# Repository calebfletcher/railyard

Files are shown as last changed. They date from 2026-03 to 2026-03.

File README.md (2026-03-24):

# railyard
An ecosystem of boards to interface with FPGA boards with PCIe interfaces

| Board  | Description | Location | Status |
| --- | --- | --- | --- |
| timemaster | Clock Generator | [boards/timemaster](boards/timemaster/) | Prototype Received |
| hub | Central Interface Hub | [boards/hub](boards/hub/) | In Design |

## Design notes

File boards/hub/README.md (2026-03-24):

# Hub

The central interface hub for railyard.

Provides the main PCIe connector to interface with the FPGA, and supplies power to it and to the various other connected boards.

pcb image

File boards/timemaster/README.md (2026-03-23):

# Timemaster

A Si5340-based clock generator board with two clocks available via a SATA connector, and 2 clocks available via MMCX connectors. All clocks are differential.

Includes a STM32G031G8Ux microcontroller to manage the Si5340, accessible over via I2C on the JST-GH connector.

5 debug LEDs are available to the STM32.

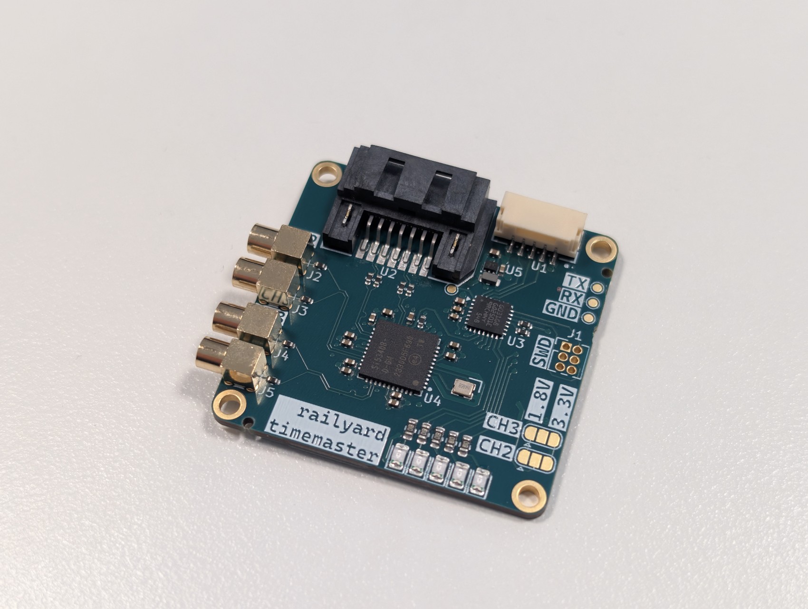
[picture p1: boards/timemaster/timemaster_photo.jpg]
pcb image


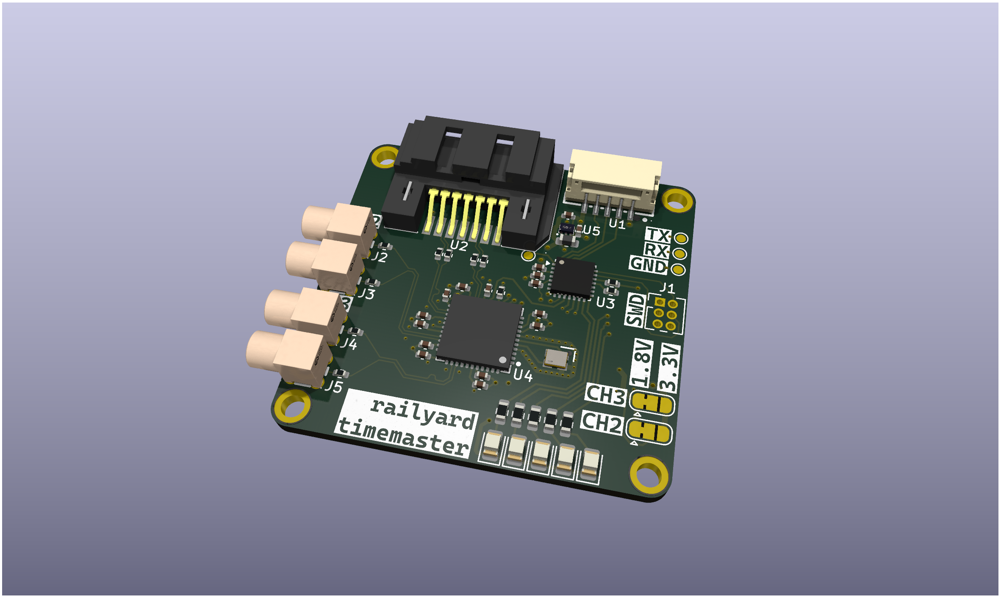
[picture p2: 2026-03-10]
boards/timemaster/timemaster_render.png

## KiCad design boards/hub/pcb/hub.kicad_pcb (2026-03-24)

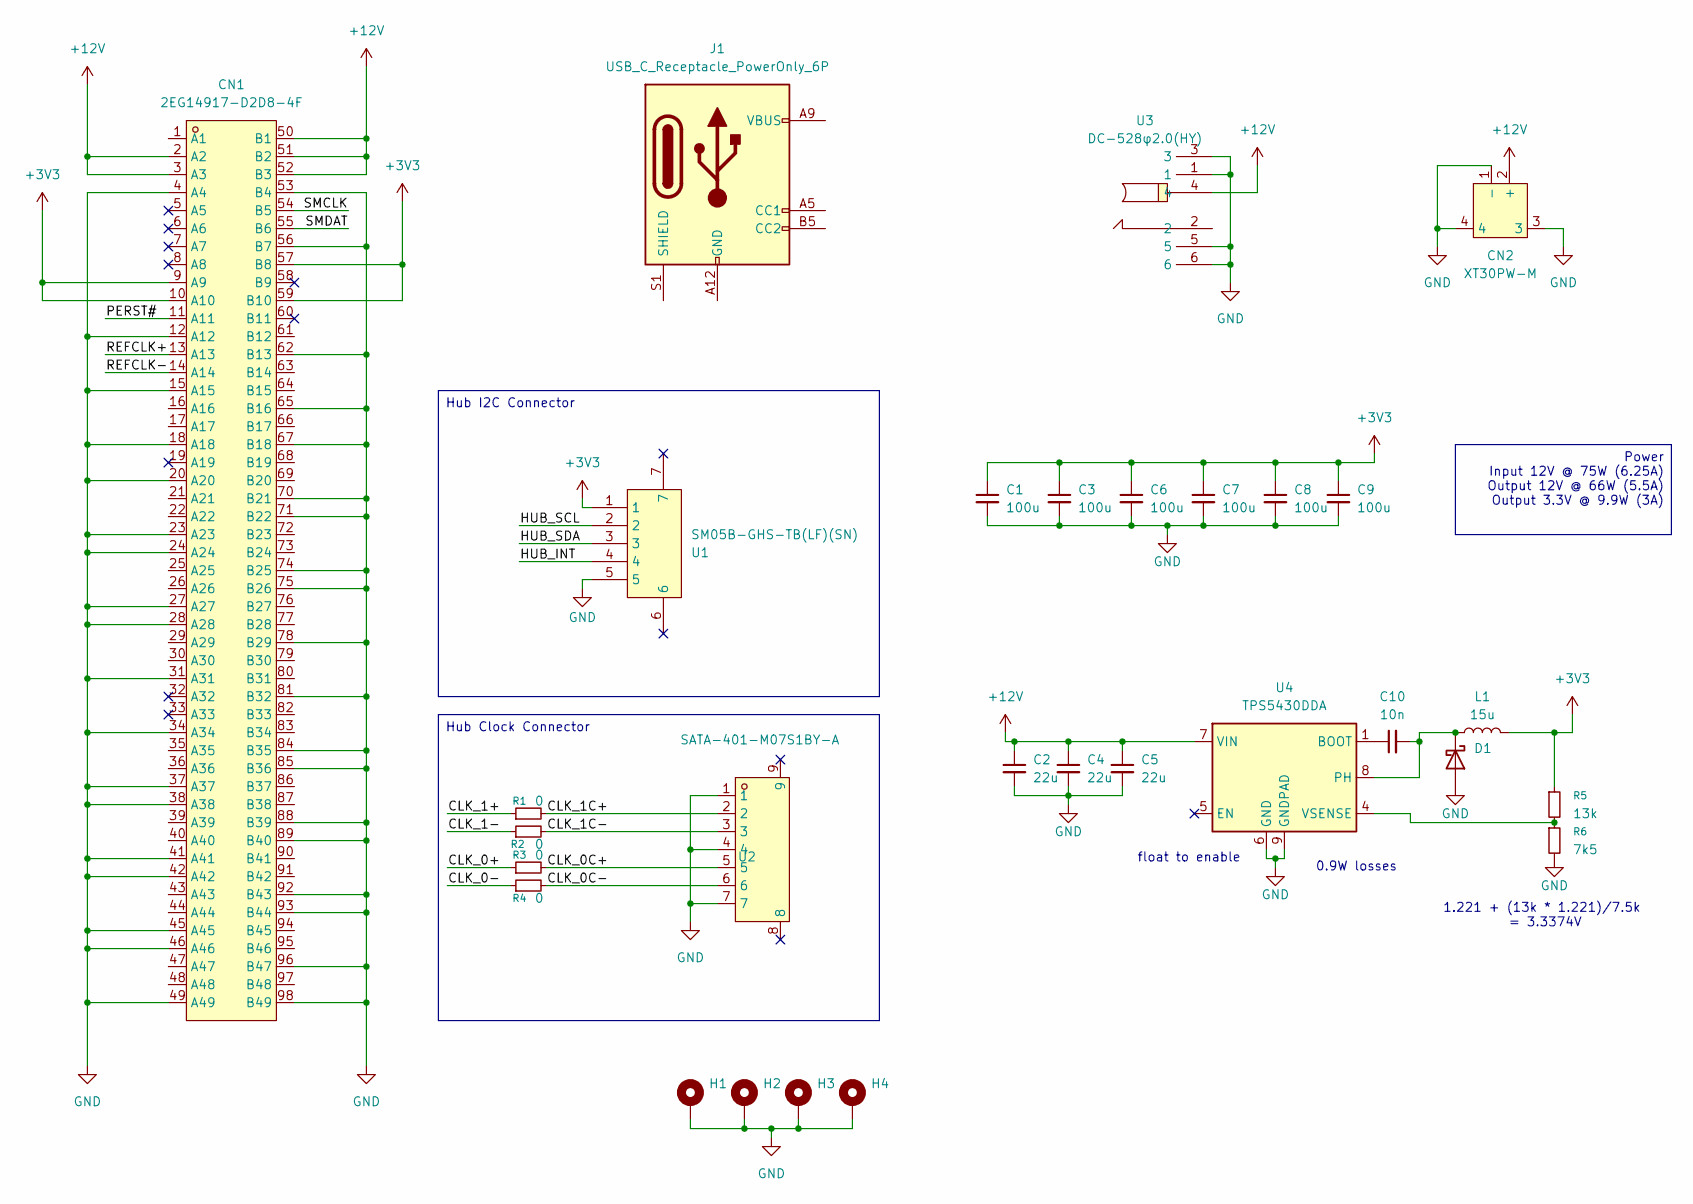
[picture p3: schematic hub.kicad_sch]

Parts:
C1, C3, C6, C7, C8, C9: 100u; C_1206_3216Metric; LCSC Part C15008
C2, C4, C5: 22u; C_0805_2012Metric; LCSC Part C45783
C10: 10n; C_0402_1005Metric; LCSC Part C15195
CN1: 2EG14917-D2D8-4F; CONN-TH_2EG14917-D2D8-4F; MPN 2EG14917-D2D8-4F; LCSC Part C426231
CN2: XT30PW-M; CONN-TH_XT30PW-M; LCSC Part C431092
D1: D_Schottky; D_SMA; LCSC Part C22452
H1, H2, H3, H4: MountingHole_Pad; MountingHole_2.2mm_M2_ISO7380_Pad
J1: USB_C_Receptacle_PowerOnly_6P; USB_C_Receptacle_GCT_USB4125-xx-x_6P_TopMnt_Horizontal
L1: 15u; L_Coilcraft_MSS1038-XXX; LCSC Part C18212714
R1, R2, R3, R4: 0; R_0402_1005Metric
R5: 13k; R_0603_1608Metric; LCSC Part C22797
R6: 7k5; R_0603_1608Metric; LCSC Part C23234
U1: SM05B-GHS-TB(LF)(SN); CONN-SMD_5P-P1.25_SM05B-GHS-TB-LF-SN; LCSC Part C189896
U2: SATA-401-M07S1BY-A; CONN-SMD_SATA-401-M07S1BY-A; LCSC Part C7500835
U3: DC-528φ2.0(HY); DC-IN-TH_DC-528-2.0-HY; LCSC Part C2851176
U4: TPS5430DDA; TI_SO-PowerPAD-8_ThermalVias; LCSC Part C9864

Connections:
+3V3: C1.1, C3.1, C6.1, C7.1, C8.1, C9.1, CN1.9 (A9), CN1.10 (A10), CN1.57 (B8), CN1.59 (B10), L1.2, R5.1, U1.1
+12V: C2.1, C4.1, C5.1, CN1.2 (A2), CN1.3 (A3), CN1.50 (B1), CN1.51 (B2), CN1.52 (B3), CN2.2 (+), U3.4, U4.7 (VIN)
/CLK_0+: R3.1
/CLK_0-: R4.1
/CLK_0C+: R3.2, U2.5
/CLK_0C-: R4.2, U2.6
/CLK_1+: R1.1
/CLK_1-: R2.1
/CLK_1C+: R1.2, U2.2
/CLK_1C-: R2.2, U2.3
/HUB_INT: U1.4
/HUB_SCL: U1.2
/HUB_SDA: U1.3
/PERST#: CN1.11 (A11)
/REFCLK+: CN1.13 (A13)
/REFCLK-: CN1.14 (A14)
/SMCLK: CN1.54 (B5)
/SMDAT: CN1.55 (B6)
GND: C1.2, C2.2, C3.2, C4.2, C5.2, C6.2, C7.2, C8.2, C9.2, CN1.4 (A4), CN1.12 (A12), CN1.15 (A15), CN1.18 (A18), CN1.20 (A20), CN1.23 (A23), CN1.24 (A24), CN1.27 (A27), CN1.28 (A28), CN1.31 (A31), CN1.34 (A34), CN1.37 (A37), CN1.38 (A38), CN1.41 (A41), CN1.42 (A42), CN1.45 (A45), CN1.46 (A46), CN1.49 (A49), CN1.53 (B4), CN1.56 (B7), CN1.62 (B13), CN1.65 (B16), CN1.67 (B18), CN1.70 (B21), CN1.71 (B22), CN1.74 (B25), CN1.75 (B26), CN1.78 (B29), CN1.81 (B32), CN1.84 (B35), CN1.85 (B36), CN1.88 (B39), CN1.89 (B40), CN1.92 (B43), CN1.93 (B44), CN1.96 (B47), CN1.98 (B49), CN2.1 (-), CN2.3, CN2.4, D1.2 (A), H1.1, H2.1, H3.1, H4.1, R6.2, U1.5, U2.1, U2.4, U2.7, U3.1, U3.3, U3.5, U3.6, U4.6 (GND), U4.9 (GNDPAD)
unnamed: C10.2, D1.1 (K), L1.1, U4.8 (PH)
unnamed: J1.A12 (GND), J1.B12 (GND)
unnamed: J1.A9 (VBUS), J1.B9 (VBUS)
unnamed: C10.1, U4.1 (BOOT)
unnamed: R5.2, R6.1, U4.4 (VSENSE)

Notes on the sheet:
0.9W losses
float to enable
1.221 + (13k * 1.221)/7.5k = 3.3374V
Power Input 12V @ 75W (6.25A) Output 12V @ 66W (5.5A) Output 3.3V @ 9.9W (3A)
Hub Clock Connector
Hub I2C Connector

Board: 2 copper layers, 27 parts (0 on the bottom side), 12 nets, no tracks yet.

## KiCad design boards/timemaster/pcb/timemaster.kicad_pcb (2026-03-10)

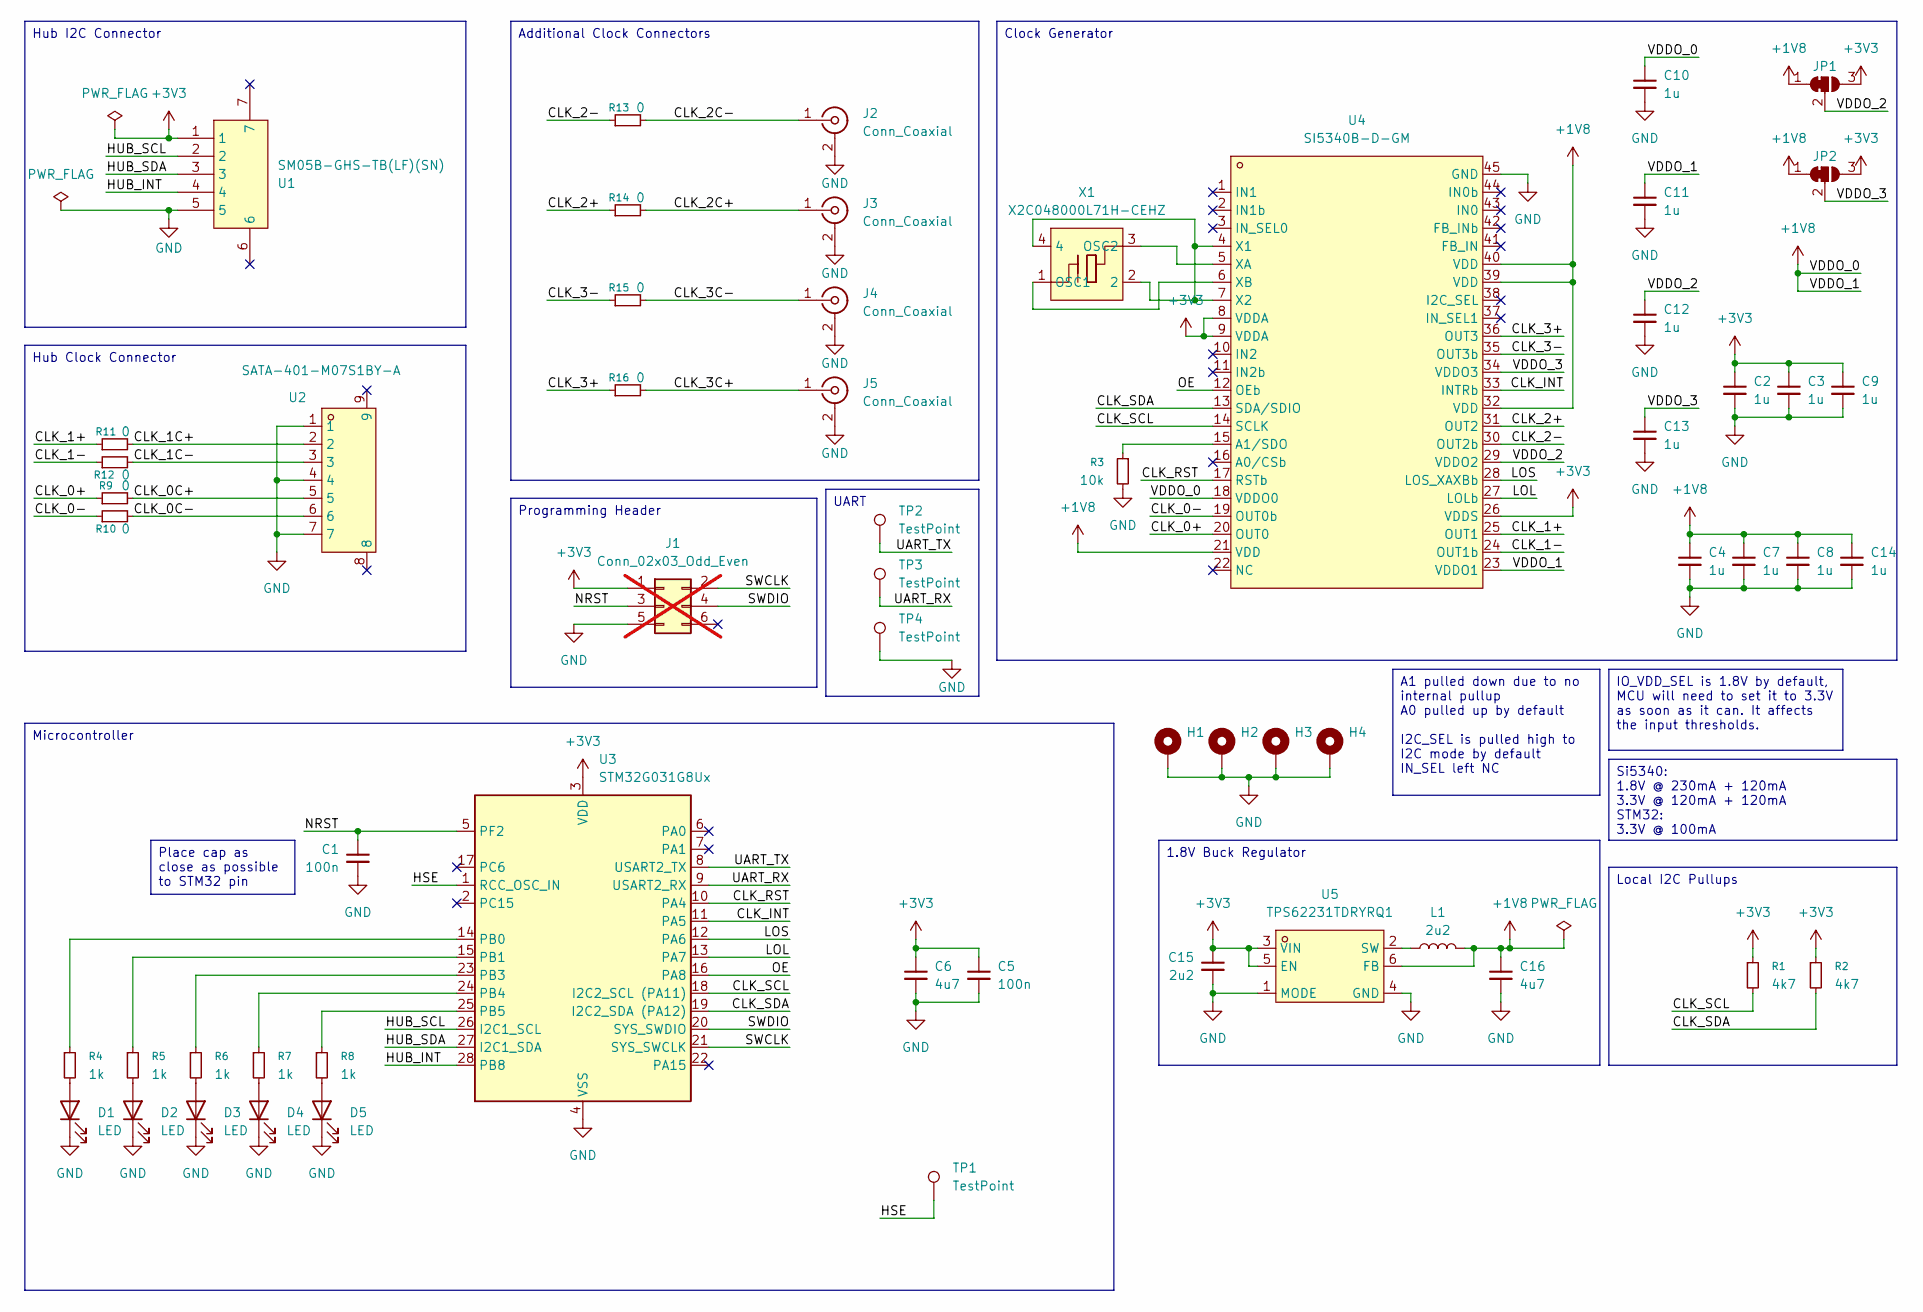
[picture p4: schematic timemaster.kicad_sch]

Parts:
C1, C5: 100n; C_0402_1005Metric
C2, C3, C4, C7, C8, C9, C10, C11, C12, C13, C14: 1u; C_0402_1005Metric
C6, C16: 4u7; C_0402_1005Metric
C15: 2u2; C_0402_1005Metric
D1, D2, D3, D4, D5: LED; LED_0805_2012Metric; LCSC Part C2297
H1, H2, H3, H4: MountingHole_Pad; MountingHole_2.2mm_M2_ISO7380_Pad
J1: Conn_02x03_Odd_Even; PinHeader_2x03_P1.27mm_Vertical; not fitted
J2, J3, J4, J5: Conn_Coaxial; MMCX-TH_DL-MMCX-KWE
JP1, JP2: SolderJumper_3_Bridged12; SolderJumper-3_P1.3mm_Bridged12_RoundedPad1.0x1.5mm
L1: 2u2; L_0603_1608Metric; LCSC Part C48888123
R1, R2: 4k7; R_0402_1005Metric
R3: 10k; R_0402_1005Metric
R4, R5, R6, R7, R8: 1k; R_0603_1608Metric
R9, R10, R11, R12, R13, R14, R15, R16: 0; R_0402_1005Metric
TP1, TP2, TP3, TP4: TestPoint; TestPoint_Pad_D1.0mm
U1: SM05B-GHS-TB(LF)(SN); CONN-SMD_5P-P1.25_SM05B-GHS-TB-LF-SN; LCSC Part C189896
U2: SATA-401-M07S1BY-A; CONN-SMD_SATA-401-M07S1BY-A; LCSC Part C7500835
U3: STM32G031G8Ux; QFN-28_4x4mm_P0.5mm; LCSC Part C432211
U4: SI5340B-D-GM; QFN-44_L7.0-W7.0-P0.50-TL-EP5.2; LCSC Part C3607873
U5: TPS62231TDRYRQ1; XSON-6_L1.5-W1.0-P0.50-S0.60-BR; LCSC Part C2070811
X1: X2C048000L71H-CEHZ; CRYSTAL-SMD_4P-L2.0-W1.6-BL; LCSC Part C254326

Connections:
+1V8: C4.1, C7.1, C8.1, C10.1, C11.1, C14.1, C16.1, JP1.1 (A), JP2.1 (A), L1.2, U4.18 (VDDO0), U4.21 (VDD), U4.23 (VDDO1), U4.32 (VDD), U4.39 (VDD), U4.40 (VDD), U5.6 (FB)
+3V3: C2.1, C3.1, C5.1, C6.1, C9.1, C15.1, J1.1, JP1.3 (B), JP2.3 (B), R1.1, R2.1, U1.1, U3.3 (VDD), U4.8 (VDDA), U4.9 (VDDA), U4.26 (VDDS), U5.3 (VIN), U5.5 (EN)
/CLK_0+: R9.1, U4.20 (OUT0)
/CLK_0-: R10.1, U4.19 (OUT0b)
/CLK_0C+: R9.2, U2.5
/CLK_0C-: R10.2, U2.6
/CLK_1+: R11.1, U4.25 (OUT1)
/CLK_1-: R12.1, U4.24 (OUT1b)
/CLK_1C+: R11.2, U2.2
/CLK_1C-: R12.2, U2.3
/CLK_2+: R14.1, U4.31 (OUT2)
/CLK_2-: R13.1, U4.30 (OUT2b)
/CLK_2C+: J3.1 (In), R14.2
/CLK_2C-: J2.1 (In), R13.2
/CLK_3+: R16.1, U4.36 (OUT3)
/CLK_3-: R15.1, U4.35 (OUT3b)
/CLK_3C+: J5.1 (In), R16.2
/CLK_3C-: J4.1 (In), R15.2
/CLK_INT: U3.11 (PA5), U4.33 (INTRb)
/CLK_RST: U3.10 (PA4), U4.17 (RSTb)
/CLK_SCL: R1.2, U3.18 (I2C2_SCL (PA11)), U4.14 (SCLK)
/CLK_SDA: R2.2, U3.19 (I2C2_SDA (PA12)), U4.13 (SDA/SDIO)
/HSE: TP1.1, U3.1 (RCC_OSC_IN)
/HUB_INT: U1.4, U3.28 (PB8)
/HUB_SCL: U1.2, U3.26 (I2C1_SCL)
/HUB_SDA: U1.3, U3.27 (I2C1_SDA)
/LOL: U3.13 (PA7), U4.27 (LOLb)
/LOS: U3.12 (PA6), U4.28 (LOS_XAXBb)
/NRST: C1.1, J1.3, U3.5 (PF2)
/OE: U3.16 (PA8), U4.12 (OEb)
/SWCLK: J1.2, U3.21 (SYS_SWCLK)
/SWDIO: J1.4, U3.20 (SYS_SWDIO)
/UART_RX: TP3.1, U3.9 (USART2_RX)
/UART_TX: TP2.1, U3.8 (USART2_TX)
/VDDO_2: C12.1, JP1.2 (C), U4.29 (VDDO2)
/VDDO_3: C13.1, JP2.2 (C), U4.34 (VDDO3)
GND: C1.2, C2.2, C3.2, C4.2, C5.2, C6.2, C7.2, C8.2, C9.2, C10.2, C11.2, C12.2, C13.2, C14.2, C15.2, C16.2, D1.1 (K), D2.1 (K), D3.1 (K), D4.1 (K), D5.1 (K), H1.1, H2.1, H3.1, H4.1, J1.5, J2.2 (Ext), J3.2 (Ext), J4.2 (Ext), J5.2 (Ext), R3.2, TP4.1, U1.5, U2.1, U2.4, U2.7, U3.4 (VSS), U4.45 (GND), U5.1 (MODE), U5.4 (GND)
unnamed: D1.2 (A), R4.2
unnamed: D2.2 (A), R5.2
unnamed: D3.2 (A), R6.2
unnamed: D4.2 (A), R7.2
unnamed: D5.2 (A), R8.2
unnamed: R4.1, U3.14 (PB0)
unnamed: R5.1, U3.15 (PB1)
unnamed: R6.1, U3.23 (PB3)
unnamed: R7.1, U3.24 (PB4)
unnamed: R8.1, U3.25 (PB5)
unnamed: R3.1, U4.15 (A1/SDO)
unnamed: U4.4 (X1), U4.7 (X2), X1.2, X1.4
unnamed: U4.5 (XA), X1.3 (OSC2)
unnamed: U4.6 (XB), X1.1 (OSC1)
unnamed: L1.1, U5.2 (SW)

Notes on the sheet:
Local I2C Pullups
Hub I2C Connector
UART
Programming Header
Place cap as close as possible to STM32 pin
A1 pulled down due to no internal pullup A0 pulled up by default I2C_SEL is pulled high to I2C mode by default IN_SEL left NC
Hub Clock Connector
Si5340: 1.8V @ 230mA + 120mA 3.3V @ 120mA + 120mA STM32: 3.3V @ 100mA
IO_VDD_SEL is 1.8V by default, MCU will need to set it to 3.3V as soon as it can. It affects the input thresholds.
Microcontroller
1.8V Buck Regulator
Clock Generator
Additional Clock Connectors

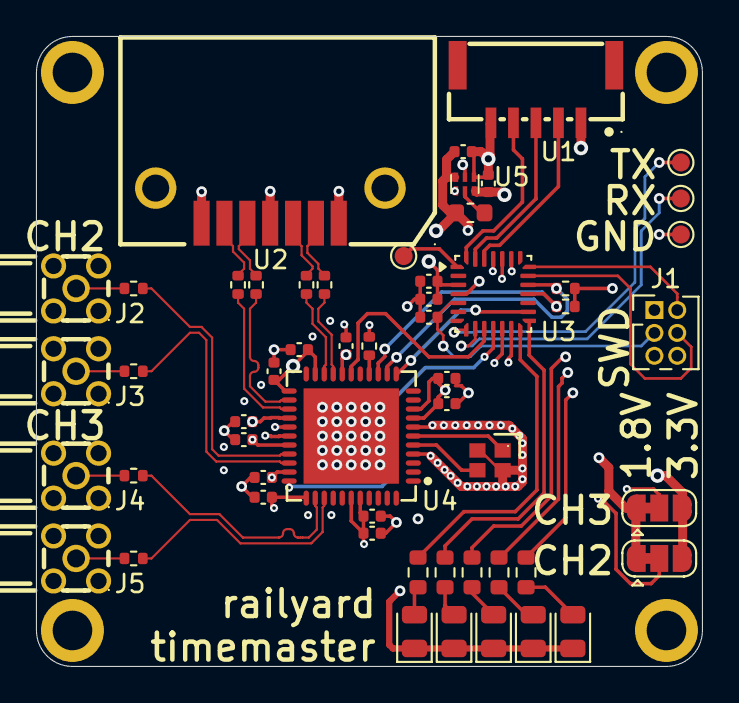
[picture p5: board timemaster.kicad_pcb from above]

Board: 6 copper layers, 37.0 x 35.0 mm, 59 parts (0 on the bottom side), 52 nets.

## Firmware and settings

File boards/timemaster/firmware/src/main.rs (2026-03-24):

#![no_main]
#![no_std]

use defmt_rtt as _;
use embassy_stm32::rcc::Pll;
use panic_probe as _;

use defmt::info;
use embassy_stm32::gpio::{Level, Speed};
use rtic_monotonics::Monotonic as _;
use rtic_monotonics::fugit::ExtU32;

rtic_monotonics::systick_monotonic!(Mono, 10000);

embassy_stm32::bind_interrupts!(struct Irqs {
    I2C2 => embassy_stm32::i2c::EventInterruptHandler<embassy_stm32::peripherals::I2C2>, embassy_stm32::i2c::ErrorInterruptHandler<embassy_stm32::peripherals::I2C2>;
    DMA1_CHANNEL1 => embassy_stm32::dma::InterruptHandler<embassy_stm32::peripherals::DMA1_CH1>;
    DMA1_CHANNEL2_3  => embassy_stm32::dma::InterruptHandler<embassy_stm32::peripherals::DMA1_CH2>;
});

#[rtic::app(device = embassy_stm32::pac, peripherals = false, dispatchers = [SPI1, SPI2])]
mod app {

    use si5340::Si5340;

    use super::*;

    #[shared]
    struct Shared {}

    #[local]
    struct Local {
        clk_i2c: embassy_stm32::i2c::I2c<
            'static,
            embassy_stm32::mode::Async,
            embassy_stm32::i2c::mode::Master,
        >,
    }

    #[init]
    fn init(cx: init::Context) -> (Shared, Local) {
        info!("starting timemaster");

        let p = init_core();

        // Setup clocks and systick timer for delays
        let clocks = embassy_stm32::rcc::clocks(&p.RCC);
        let sysclk = clocks.sys.to_hertz().unwrap();
        info!("running with sysclk: {}", sysclk);
        Mono::start(cx.core.SYST, sysclk.0);

        // Start health blinking led
        let health_led = embassy_stm32::gpio::Output::new(p.PB5, Level::Low, Speed::Low);
        blink_led::spawn(health_led).ok();

        let clk_i2c = embassy_stm32::i2c::I2c::new(
            p.I2C2,
            p.PA11,
            p.PA12,
            p.DMA1_CH1,
            p.DMA1_CH2,
            Irqs,
            embassy_stm32::i2c::Config::default(),
        );

        check_i2c::spawn().ok();

        (Shared {}, Local { clk_i2c })
    }

    /// Blink one of the LEDs to show the system is alive
    #[task]
    async fn blink_led(_: blink_led::Context<'_>, mut led: embassy_stm32::gpio::Output<'static>) {
        loop {
            led.set_high();
            Mono::delay(100.millis()).await;
            led.set_low();
            Mono::delay(900.millis()).await;
        }
    }

    #[task(local = [clk_i2c])]
    async fn check_i2c(cx: check_i2c::Context<'_>) {
        let i2c = cx.local.clk_i2c;
        let mut _device = Si5340::new_i2c(i2c, si5340::Address::from_pins(true, false));
    }
}

/// Initialise the HAL with the required RCC clock configuration.
fn init_core() -> embassy_stm32::Peripherals {
    let mut config = embassy_stm32::Config::default();
    // PLL main output of (16MHz / 2) * (16 / 2) = 64MHz
    config.rcc.pll = Some(Pll {
        source: embassy_stm32::rcc::PllSource::HSI,
        prediv: embassy_stm32::rcc::PllPreDiv::DIV2,
        mul: embassy_stm32::rcc::PllMul::MUL16,
        divp: None,
        divq: None,
        divr: Some(embassy_stm32::rcc::PllRDiv::DIV2),
    });
    // SYSCLK from PLL R output
    config.rcc.sys = embassy_stm32::rcc::Sysclk::PLL1_R;
    config.rcc.ahb_pre = embassy_stm32::rcc::AHBPrescaler::DIV1;

    embassy_stm32::init(config)
}

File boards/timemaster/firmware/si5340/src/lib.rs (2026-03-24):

#![no_std]

use embedded_hal::i2c::Operation;

pub struct Si5340<I: RegisterInterface> {
    interface: I,
}

impl<I2C: embedded_hal::i2c::I2c> Si5340<I2c<I2C>> {
    pub fn new_i2c(i2c: I2C, addr: Address) -> Self {
        let mut device = Self {
            interface: I2c { i2c, addr },
        };

        assert!(device.device_ready());
        assert_eq!(device.part_number(), 5340);

        device
    }
}

impl<I: RegisterInterface> Si5340<I> {
    pub fn register(&mut self, register: u16) -> u8 {
        self.interface.read_single(register as u8)
    }

    /// Read the part number from the device, should be 5340 to the Si5340.
    pub fn part_number(&mut self) -> u16 {
        let mut bytes = [0; 2];
        self.interface.read_multi(0x0002, &mut bytes);

        // convert to u16
        let chars = [bytes[1] >> 4, bytes[1] & 0xF, bytes[0] >> 4, bytes[0] & 0xF];
        chars[0] as u16 * 1000 + chars[1] as u16 * 100 + chars[2] as u16 * 10 + chars[3] as u16
    }

    /// Check whether the device is ready for read/write access to its registers.
    pub fn device_ready(&mut self) -> bool {
        // This register exists on all pages, no need to switch pages
        self.interface.read_single(0xFE) == 0x0F
    }
}

pub struct Address(pub u8);

impl Address {
    /// Calculate the I2C address of the device based on the known state of
    /// the a0 and a1 pins.
    pub fn from_pins(a0: bool, a1: bool) -> Self {
        Self(0b1110100 | (a1 as u8) << 1 | a0 as u8)
    }
}

pub trait RegisterInterface {
    /// Write a single byte to a register
    fn write_single(&mut self, register: u8, data: u8);
    /// Write a series of bytes from the given start register, auto-incrementing
    /// the register
    fn write_multi(&mut self, start_register: u8, data: &[u8]);

    /// Read a single byte from a register
    fn read_single(&mut self, register: u8) -> u8;
    /// Read a series of bytes from the given start register, auto-incrementing
    /// the register
    fn read_multi(&mut self, start_register: u8, data: &mut [u8]);
}

pub struct I2c<I: embedded_hal::i2c::I2c> {
    i2c: I,
    addr: Address,
}

impl<I: embedded_hal::i2c::I2c> RegisterInterface for I2c<I> {
    fn write_single(&mut self, register: u8, data: u8) {
        self.i2c.write(self.addr.0, &[register, data]).unwrap();
    }

    fn write_multi(&mut self, start_register: u8, data: &[u8]) {
        self.i2c
            .transaction(
                self.addr.0,
                &mut [Operation::Write(&[start_register]), Operation::Write(data)],
            )
            .unwrap();
    }

    fn read_single(&mut self, register: u8) -> u8 {
        // Per family reference manual, reads are two separate stages (no repeated start)
        let mut value = [0];
        self.i2c.write(self.addr.0, &[register]).unwrap();
        self.i2c.read(self.addr.0, &mut value).unwrap();
        value[0]
    }

    fn read_multi(&mut self, start_register: u8, data: &mut [u8]) {
        // Per family reference manual, reads are two separate stages (no repeated start)
        self.i2c.write(self.addr.0, &[start_register]).unwrap();
        self.i2c.read(self.addr.0, data).unwrap();
    }
}

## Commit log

2026-03-10 timemaster: initial commit
    [timemaster.kicad_pcb, timemaster.kicad_sch]
2026-03-10 update project name to railyard
2026-03-10 timemaster: rev b with larger vias for jlc
    [timemaster.kicad_pcb, timemaster.kicad_sch]
2026-03-24 hub: initial schematic planning
    [hub.kicad_pcb, hub.kicad_sch]
